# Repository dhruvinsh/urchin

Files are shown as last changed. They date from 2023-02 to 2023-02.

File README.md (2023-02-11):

# Ursa - Urchin on Steroids

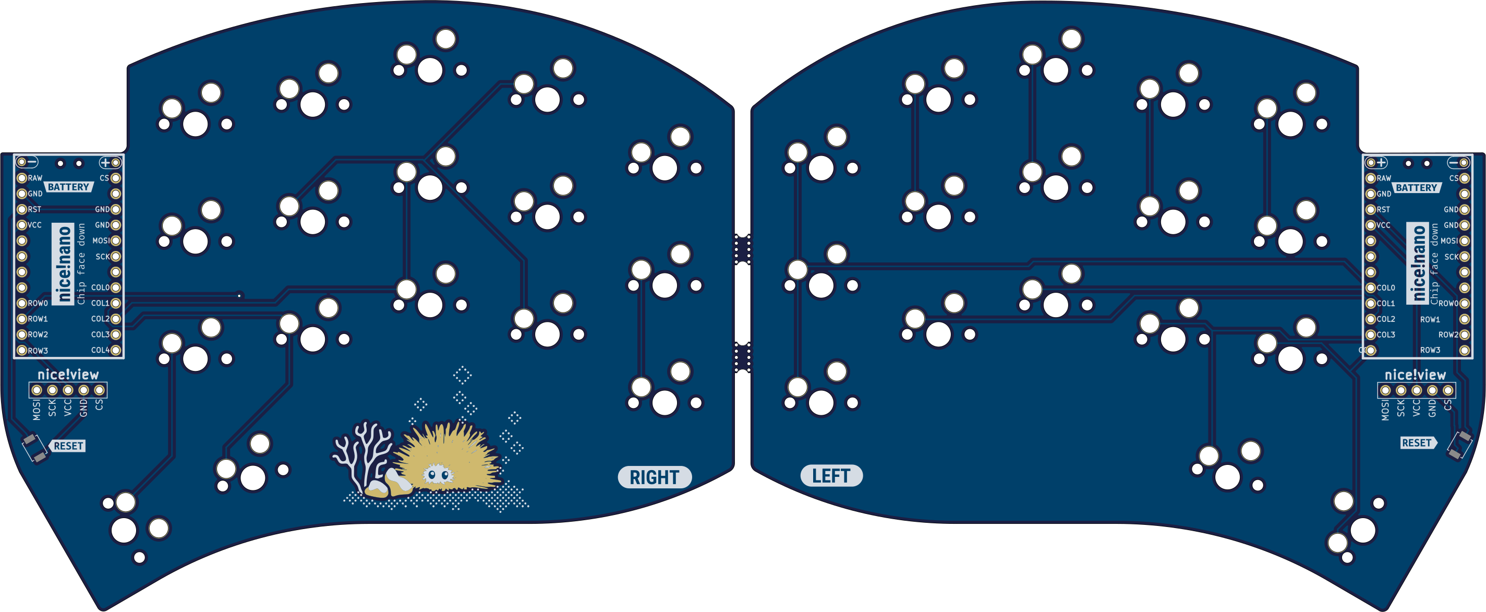
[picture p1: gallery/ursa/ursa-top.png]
PCB Preview


<span>
  
  <a href="https://github.com/duckyb/urchin/releases">
    
    
  </a>
  
</span>

I created this design because I like the [Urchin](https://github.com/duckyb/urchin) and wanted to try something with 34 keys.  
**This is a strictly wireless-only design, and is only compatible with ZMK / nice!nano. Only Cherry MX switches + Hotswap are suported!**

> Q: Why is this not just another one?  
*A: Original Urchin is based of choc switch. They are good but I still wanted to try something with MX keycaps. Hence we are here looking at the new keeyboard Ursa.*

**If you enjoy my work, please consider ⭐ starring and/or ❤ sponsoring it.**

## Features
- [x] Design fully optimized for wireless    
- [x] Native nice!view support  
- [x] Familiar Ferris/Sweep/Urchin layout  
- [x] Improved outline shape  
- [x] Support for Cherry MX Socket
- [x] Remove diode footprint from the top surface

### Upcoming
- [ ] Mounting points for cases
- [ ] Plate file
- [ ] MCU Cover file
- [ ] Tray case 3D model

## Part list (for both sides)
#### Required
- 1× PCB Kit (files for it are in [releases](https://github.com/duckyb/urchin/releases))
- 34× Kailh **MX** Hotswap Sockets
- 34× MX Compatible switches
- 34× Keycaps
- 34× SMD diodes (SOD-123)
- 2× nice!nano
- 2× Lipo battery (301230)
- 48× mill-max machined pins
- 2× Pair of female headers
#### Optional
- 2× nice!view
- 2× Reset switch (B3U-1000P(M))
- 2× Power switch (MSK 12C02)
- 10× adhesive silicone feet

## Reference build guide:

<a href="https://youtu.be/CHSh1-dJq24" target="_blank">

</a>

## Firmware
Coming soon but for now you can refere to below,

> Urchin supports ZMK only. To get started with ZMK visit the [zmk-urchin repository](https://github.com/duckyb/zmk-urchin) and follow the provided instructions.

## Credits
- Urchin by [duckyb](https://github.com/duckyb/urchin)

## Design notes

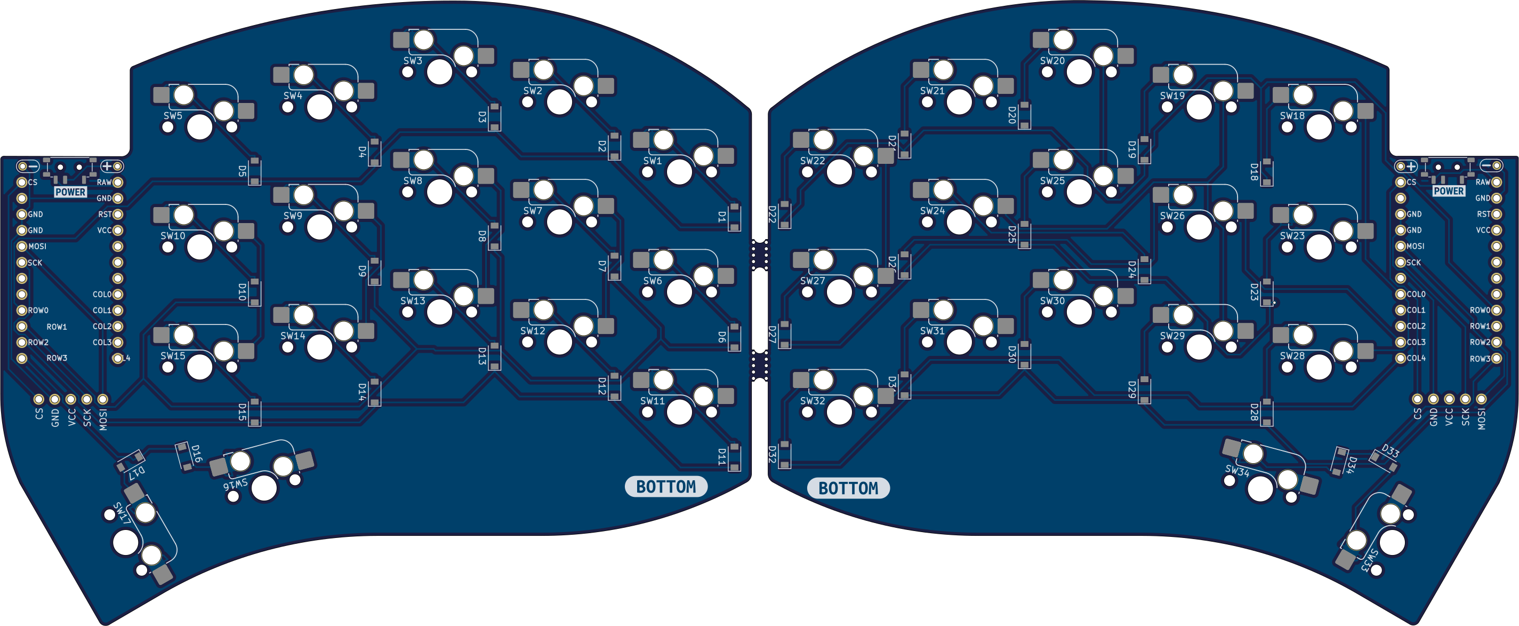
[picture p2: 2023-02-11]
gallery/ursa/ursa-bottom.png

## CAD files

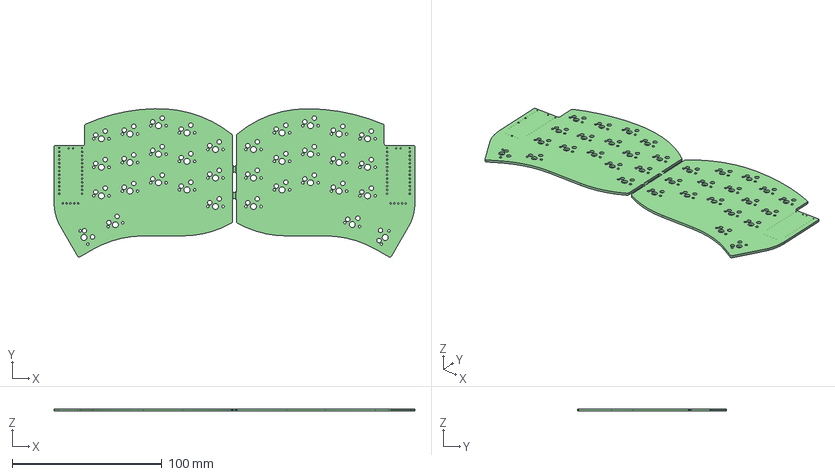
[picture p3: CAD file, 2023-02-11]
3d/ursa.step
241.2 x 99.2 x 1.60 mm

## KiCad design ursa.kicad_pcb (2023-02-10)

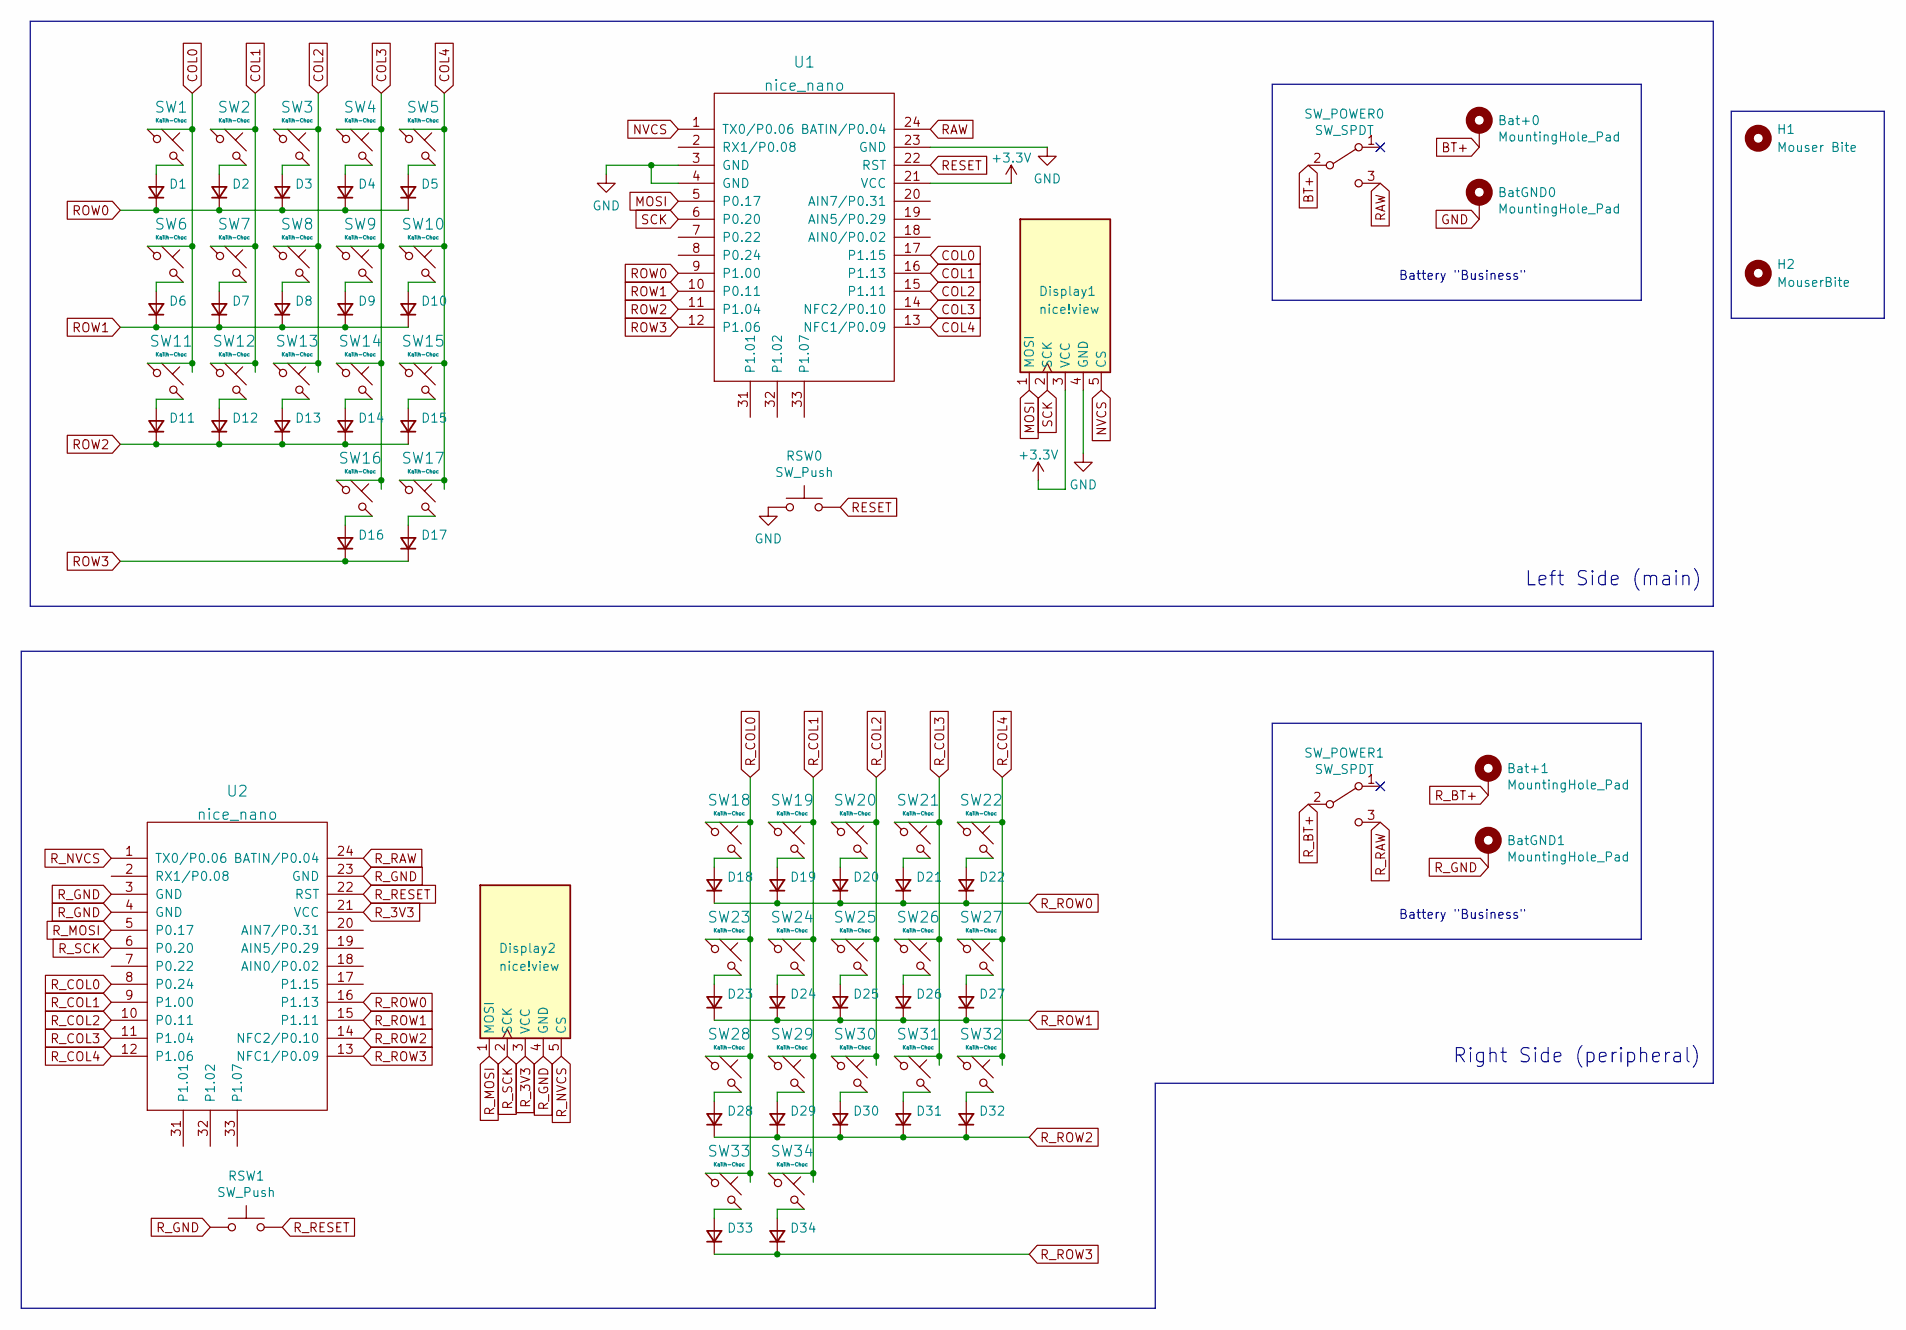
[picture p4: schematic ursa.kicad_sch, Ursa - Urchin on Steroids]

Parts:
Bat+0, Bat+1: MountingHole_Pad; 1pin_conn
BatGND0, BatGND1: MountingHole_Pad; 1pin_conn
D1, D2, D3, D4, D5, D6, D7, D8, D9, D10, D11, D12, D13, D14, D15, D16, D17, D18, D19, D20, D21, D22, D23, D24, D25, D26, D27, D28, D29, D30, D31, D32, D33, D34: diode; D_SOD-123
Display1, Display2: nice!view; nice_view
H1: Mouser Bite; mouse-bite-2mm-slot-with-space-for-track
H2: MouserBite; mouse-bite-2mm-slot-with-space-for-track
RSW0, RSW1: SW_Push; SW_RESET
SW1, SW2, SW3, SW4, SW5, SW6, SW7, SW8, SW9, SW10, SW11, SW12, SW13, SW14, SW15, SW16, SW17, SW18, SW19, SW20, SW21, SW22, SW23, SW24, SW25, SW26, SW27, SW28, SW29, SW30, SW31, SW32, SW33, SW34: Kailh-Choc; SW_MX_HS_1u
SW_POWER0, SW_POWER1: SW_SPDT; SW_MSK12C02-HB
U1, U2: nice_nano

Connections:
+3V3: Display1.3 (VCC), U1.21 (VCC)
BT+: Bat+0.1, SW_POWER0.2 (B)
COL0: SW1.1, SW6.1, SW11.1, U1.17 (P1.15)
COL1: SW2.1, SW7.1, SW12.1, U1.16 (P1.13)
COL2: SW3.1, SW8.1, SW13.1, U1.15 (P1.11)
COL3: SW4.1, SW9.1, SW14.1, SW16.1, U1.14 (NFC2/P0.10)
COL4: SW5.1, SW10.1, SW15.1, SW17.1, U1.13 (NFC1/P0.09)
GND: BatGND0.1, Display1.4 (GND), RSW0.1, U1.3 (GND), U1.4 (GND), U1.23 (GND)
MOSI: Display1.1 (MOSI), U1.5 (P0.17)
NVCS: Display1.5 (CS), U1.1 (TX0/P0.06)
unnamed: D1.2 (A), SW1.2
unnamed: D2.2 (A), SW2.2
unnamed: D3.2 (A), SW3.2
unnamed: D4.2 (A), SW4.2
unnamed: D5.2 (A), SW5.2
unnamed: D6.2 (A), SW6.2
unnamed: D7.2 (A), SW7.2
unnamed: D8.2 (A), SW8.2
unnamed: D9.2 (A), SW9.2
unnamed: D10.2 (A), SW10.2
unnamed: D11.2 (A), SW11.2
unnamed: D12.2 (A), SW12.2
unnamed: D13.2 (A), SW13.2
unnamed: D14.2 (A), SW14.2
unnamed: D15.2 (A), SW15.2
unnamed: D16.2 (A), SW16.2
unnamed: D17.2 (A), SW17.2
unnamed: D18.2 (A), SW18.2
unnamed: D19.2 (A), SW19.2
unnamed: D20.2 (A), SW20.2
unnamed: D21.2 (A), SW21.2
unnamed: D22.2 (A), SW22.2
unnamed: D23.2 (A), SW23.2
unnamed: D24.2 (A), SW24.2
unnamed: D25.2 (A), SW25.2
unnamed: D26.2 (A), SW26.2
unnamed: D27.2 (A), SW27.2
unnamed: D28.2 (A), SW28.2
unnamed: D29.2 (A), SW29.2
unnamed: D30.2 (A), SW30.2
unnamed: D31.2 (A), SW31.2
unnamed: D32.2 (A), SW32.2
unnamed: D33.2 (A), SW33.2
unnamed: D34.2 (A), SW34.2
RAW: SW_POWER0.3 (C), U1.24 (BATIN/P0.04)
RESET: RSW0.2, U1.22 (RST)
ROW0: D1.1 (K), D2.1 (K), D3.1 (K), D4.1 (K), D5.1 (K), U1.9 (P1.00)
ROW1: D6.1 (K), D7.1 (K), D8.1 (K), D9.1 (K), D10.1 (K), U1.10 (P0.11)
ROW2: D11.1 (K), D12.1 (K), D13.1 (K), D14.1 (K), D15.1 (K), U1.11 (P1.04)
ROW3: D16.1 (K), D17.1 (K), U1.12 (P1.06)
R_3V3: Display2.3 (VCC), U2.21 (VCC)
R_BT+: Bat+1.1, SW_POWER1.2 (B)
R_COL0: SW18.1, SW23.1, SW28.1, SW33.1, U2.8 (P0.24)
R_COL1: SW19.1, SW24.1, SW29.1, SW34.1, U2.9 (P1.00)
R_COL2: SW20.1, SW25.1, SW30.1, U2.10 (P0.11)
R_COL3: SW21.1, SW26.1, SW31.1, U2.11 (P1.04)
R_COL4: SW22.1, SW27.1, SW32.1, U2.12 (P1.06)
R_GND: BatGND1.1, Display2.4 (GND), RSW1.1, U2.3 (GND), U2.4 (GND), U2.23 (GND)
R_MOSI: Display2.1 (MOSI), U2.5 (P0.17)
R_NVCS: Display2.5 (CS), U2.1 (TX0/P0.06)
R_RAW: SW_POWER1.3 (C), U2.24 (BATIN/P0.04)
R_RESET: RSW1.2, U2.22 (RST)
R_ROW0: D18.1 (K), D19.1 (K), D20.1 (K), D21.1 (K), D22.1 (K), U2.16 (P1.13)
R_ROW1: D23.1 (K), D24.1 (K), D25.1 (K), D26.1 (K), D27.1 (K), U2.15 (P1.11)
R_ROW2: D28.1 (K), D29.1 (K), D30.1 (K), D31.1 (K), D32.1 (K), U2.14 (NFC2/P0.10)
R_ROW3: D33.1 (K), D34.1 (K), U2.13 (NFC1/P0.09)
R_SCK: Display2.2 (SCK), U2.6 (P0.20)
SCK: Display1.2 (SCK), U1.6 (P0.20)

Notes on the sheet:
Right Side (peripheral)
Battery "Business"
Left Side (main)

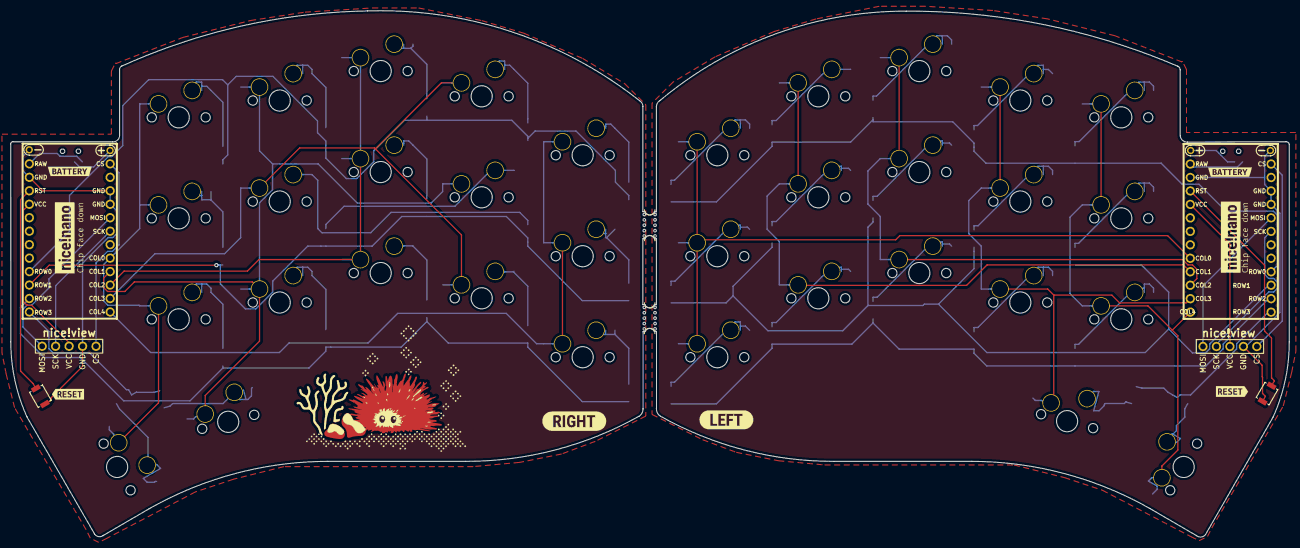
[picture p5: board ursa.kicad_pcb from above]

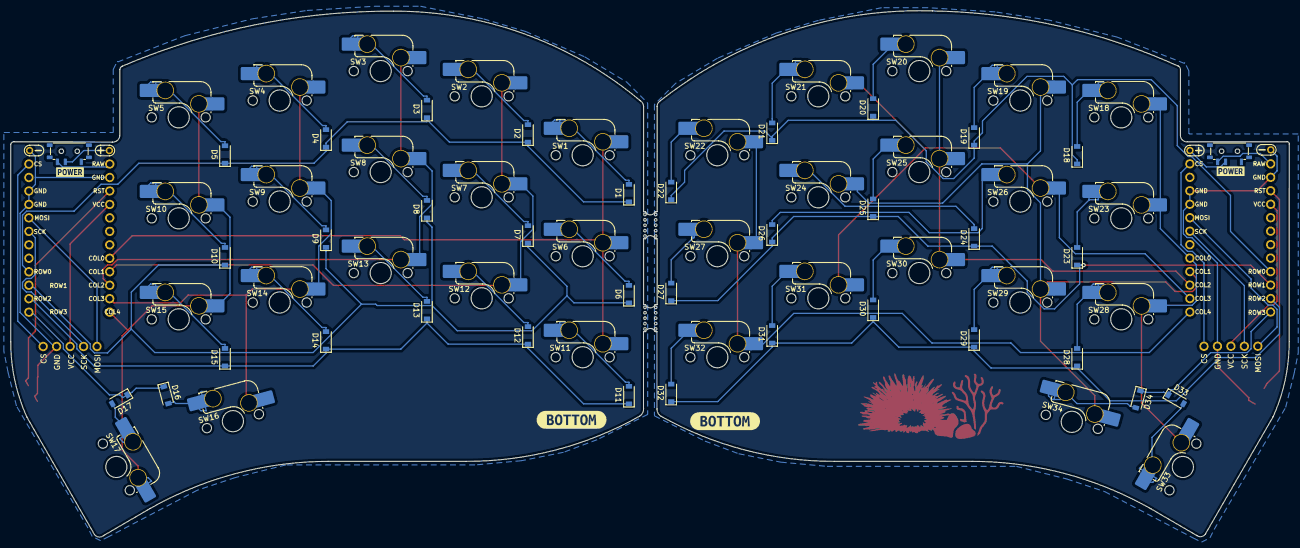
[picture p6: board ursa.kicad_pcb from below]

Board: 2 copper layers, 241.2 x 99.3 mm, 99 parts (76 on the bottom side), 68 nets.

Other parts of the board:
1-G***, 3-G***: LOGO
1-kibuzzard-636592CC: G***; kibuzzard-636592CC
2-kibuzzard-6365950B: G***; kibuzzard-6365950B
3-kibuzzard-63658865: G***; kibuzzard-63658865
4-kibuzzard-636588C8: G***; kibuzzard-636588C8
11-kibuzzard-63658823: G***; kibuzzard-63658823
12-kibuzzard-6361375E: G***; kibuzzard-6361375E
13-kibuzzard-63659465: G***; kibuzzard-63659465
kibuzzard-636588C8: G***; kibuzzard-636588C8
kibuzzard-6361375E: G***; kibuzzard-6361375E
kibuzzard-6365884B: G***; kibuzzard-6365884B
kibuzzard-6365951E: G***; kibuzzard-6365951E
kibuzzard-63658830: G***; kibuzzard-63658830
kibuzzard-63659296: G***; kibuzzard-63659296
kibuzzard-63659477: G***; kibuzzard-63659477
logo-3-G***: LOGO

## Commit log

2023-02-08 try 1: cherry footprint added
    * NOTE: this is not valid implementation. Footprint are fitting that
    does not mean that it will work on physical PCB. Need to redesign it.
    [main-B_Cu.gbr, main-B_Mask.gbr, main-B_Paste.gbr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]
2023-02-09 WIP: cherry mx supported added
    *TODO: routing still missing
    [main.kicad_pcb, main.kicad_sch]
2023-02-10 adding routes and zone
    [main.kicad_pcb, main.kicad_sch]
2023-02-10 minor update to PCB and name changes
    [main.kicad_pcb, main.kicad_sch]
2023-02-10 renamed project from urchin to ursa
    [ursa.kicad_pcb, ursa.kicad_sch]
2023-02-10 mouser bite added as library
    [ursa.kicad_pcb, ursa.kicad_sch]
2023-02-10 library changes with new routes
    [ursa.kicad_pcb, ursa.kicad_sch]
2023-02-11 3d file added
    [ursa.step]
